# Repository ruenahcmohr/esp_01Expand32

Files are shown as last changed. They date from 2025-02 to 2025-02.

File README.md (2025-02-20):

# esp_01Expand32
esp-01 (esp8266) IO expander, 16 output, 16 input = 32

internet inspired esp-01 (esp8266) IO expander.

This uses DIP (socket and replace if you oops) 74xx595 and 74xx165 chips to give you 16 inputs and 16 outputs from an esp-01

Why not just use i2c?

 WELL, the i2c chips have realy primitive IO circuits, and you cannot have a high impedence input. This means you can't tie into analog circuits like RC pairs to give you time delays, which is something important to me.

 You also can't properly drive an output high, this is also important to me.

The zip file is all the gerber files to have it made.

The regultor is an AMS1117-3.3

oh yea, the power and IO are 5V., IF YOU WANT, you can bypass the regulator and use it all with 3.3V.

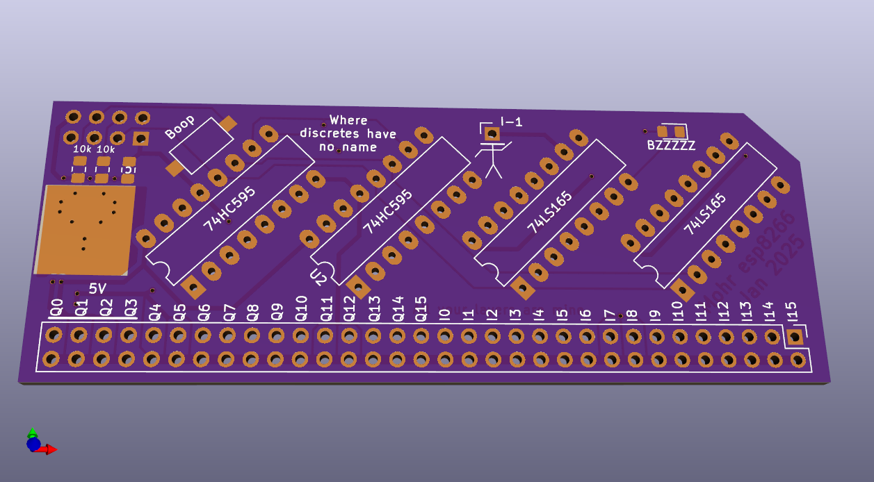
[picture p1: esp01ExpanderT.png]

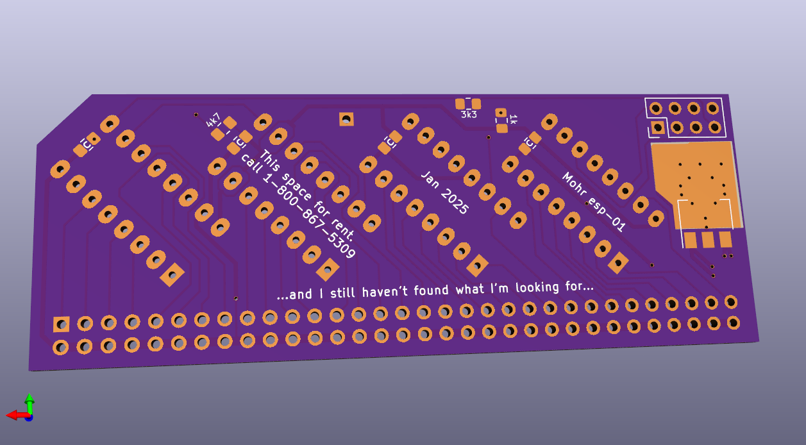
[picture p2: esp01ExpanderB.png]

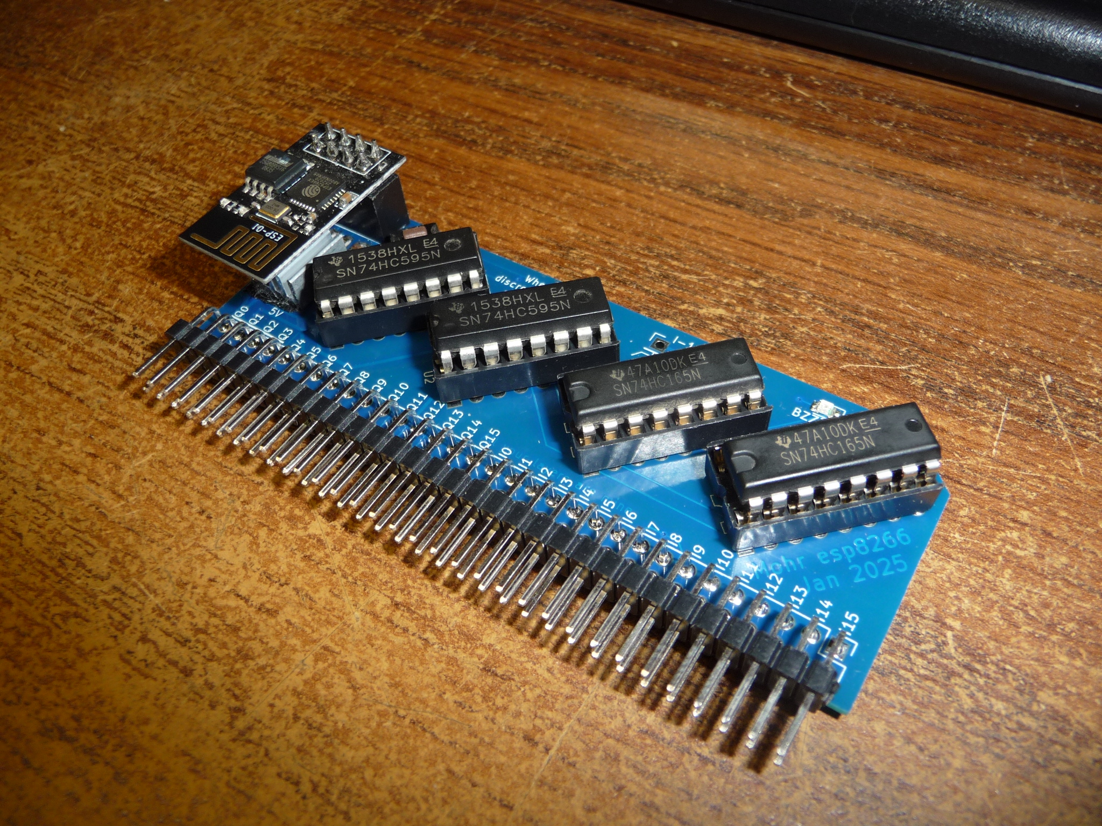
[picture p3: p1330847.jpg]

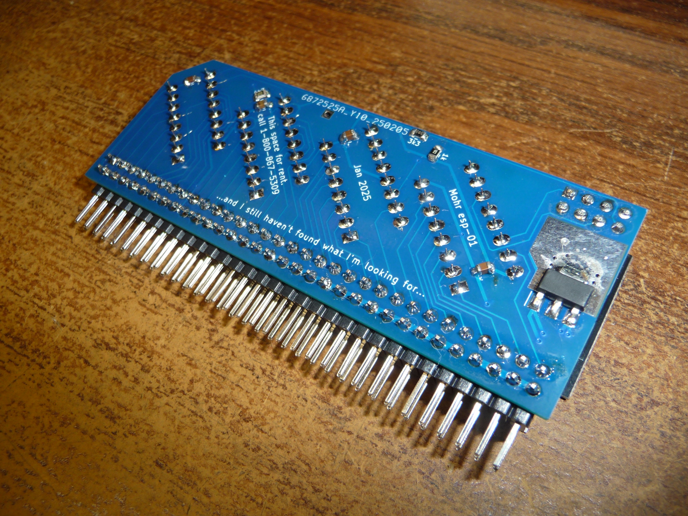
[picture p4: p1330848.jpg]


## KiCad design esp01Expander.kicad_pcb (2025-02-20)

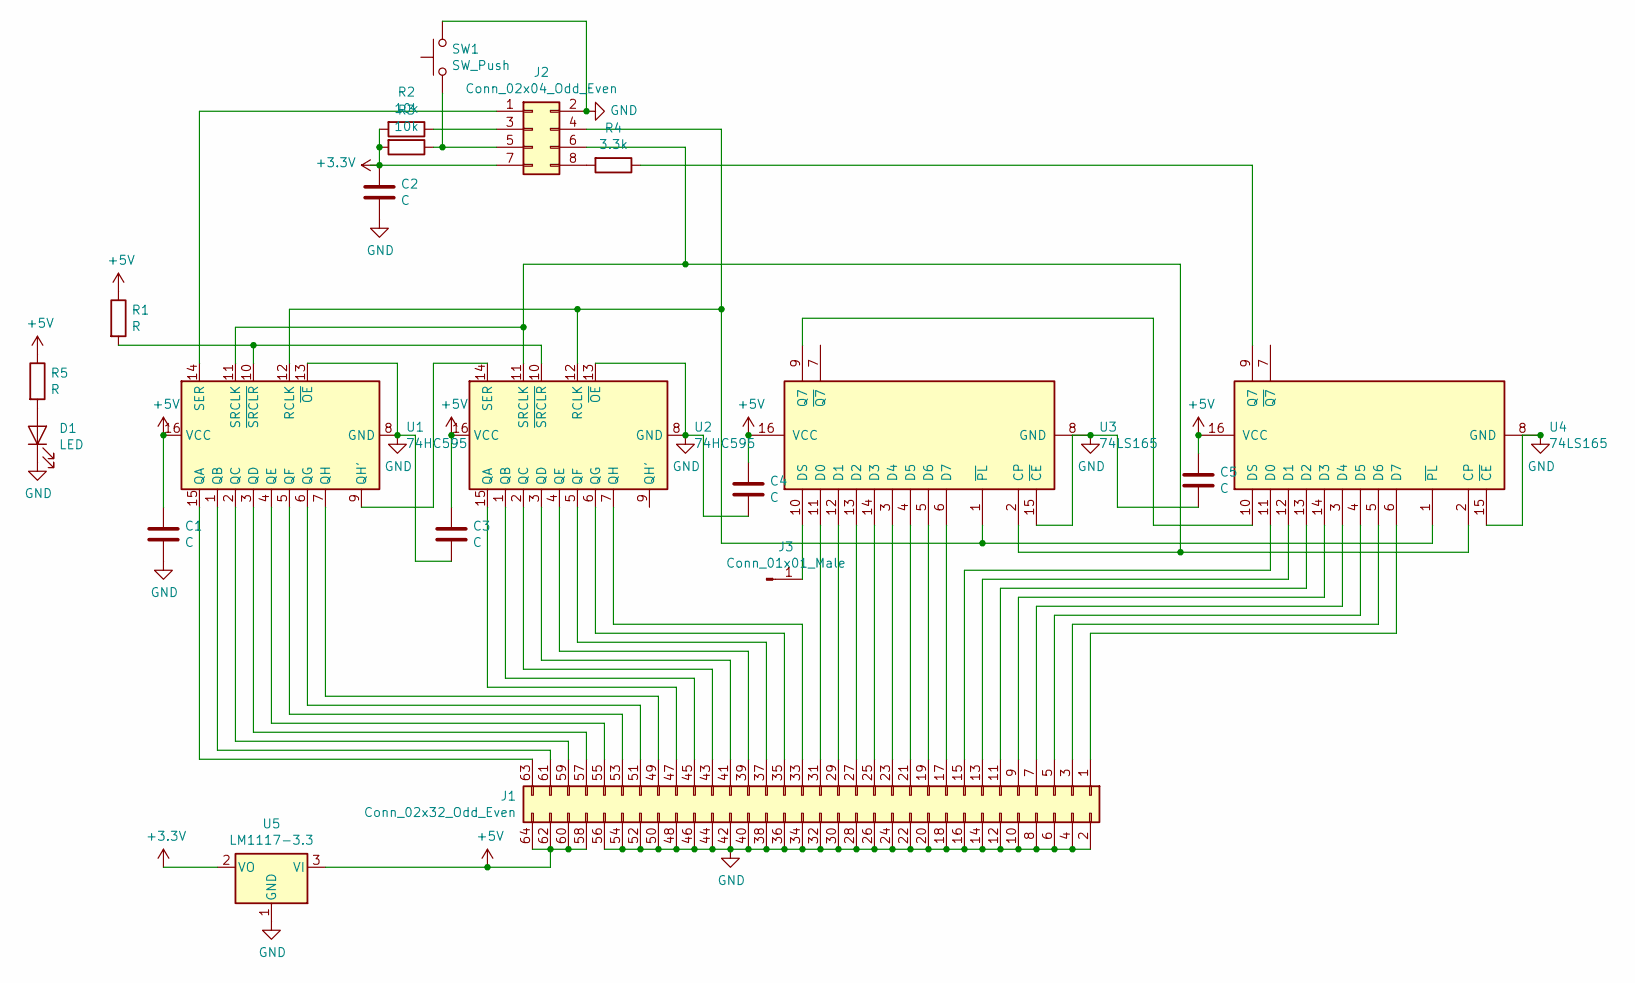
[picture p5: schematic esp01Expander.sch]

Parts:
C1, C2, C3, C4, C5: C; C_0805_2012Metric_Pad1.15x1.40mm_HandSolder
D1: LED; LED_0805_2012Metric_Pad1.15x1.40mm_HandSolder
J1: Conn_02x32_Odd_Even; PinHeader_2x32_P2.54mm_Vertical
J2: Conn_02x04_Odd_Even; PinHeader_2x04_P2.54mm_Vertical
J3: Conn_01x01_Male; PinHeader_1x01_P2.54mm_Vertical
R1, R5: R; R_0805_2012Metric_Pad1.15x1.40mm_HandSolder
R2, R3: 10k; R_0805_2012Metric_Pad1.15x1.40mm_HandSolder
R4: 3.3k; R_0805_2012Metric_Pad1.15x1.40mm_HandSolder
SW1: SW_Push; SW_SPST_CK_RS282G05A3
U1, U2: 74HC595; DIP-16_W7.62mm_LongPads
U3, U4: 74LS165; DIP-16_W7.62mm_LongPads
U5: LM1117-3.3; SOT-223-3_TabPin2

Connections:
+3V3: C2.1, J2.7, R2.2, R3.2, U5.2 (VO)
+5V: C1.1, C3.1, C4.1, C5.1, J1.58, J1.60, J1.62, J1.64, R1.1, R5.1, U1.16 (VCC), U2.16 (VCC), U3.16 (VCC), U4.16 (VCC), U5.3 (VI)
GND: C1.2, C2.2, C3.2, C4.2, C5.2, D1.1 (K), J1.2, J1.4, J1.6, J1.8, J1.10, J1.12, J1.14, J1.16, J1.18, J1.20, J1.22, J1.24, J1.26, J1.28, J1.30, J1.32, J1.34, J1.36, J1.38, J1.40, J1.42, J1.44, J1.46, J1.48, J1.50, J1.52, J1.54, J1.56, J2.2, SW1.2, U1.8 (GND), U1.13 (~OE), U2.8 (GND), U2.13 (~OE), U3.8 (GND), U3.15 (~CE), U4.8 (GND), U4.15 (~CE), U5.1 (GND)
unnamed: D1.2 (A), R5.2
unnamed: J1.1, U4.6 (D7)
unnamed: J1.3, U4.5 (D6)
unnamed: J1.5, U4.4 (D5)
unnamed: J1.7, U4.3 (D4)
unnamed: J1.9, U4.14 (D3)
unnamed: J1.11, U4.13 (D2)
unnamed: J1.13, U4.12 (D1)
unnamed: J1.15, U4.11 (D0)
unnamed: J1.17, U3.6 (D7)
unnamed: J1.19, U3.5 (D6)
unnamed: J1.21, U3.4 (D5)
unnamed: J1.23, U3.3 (D4)
unnamed: J1.25, U3.14 (D3)
unnamed: J1.27, U3.13 (D2)
unnamed: J1.29, U3.12 (D1)
unnamed: J1.31, U3.11 (D0)
unnamed: J1.33, U2.7 (QH)
unnamed: J1.35, U2.6 (QG)
unnamed: J1.37, U2.5 (QF)
unnamed: J1.39, U2.4 (QE)
unnamed: J1.41, U2.3 (QD)
unnamed: J1.43, U2.2 (QC)
unnamed: J1.45, U2.1 (QB)
unnamed: J1.47, U2.15 (QA)
unnamed: J1.49, U1.7 (QH)
unnamed: J1.51, U1.6 (QG)
unnamed: J1.53, U1.5 (QF)
unnamed: J1.55, U1.4 (QE)
unnamed: J1.57, U1.3 (QD)
unnamed: J1.59, U1.2 (QC)
unnamed: J1.61, U1.1 (QB)
unnamed: J1.63, U1.15 (QA)
unnamed: J2.1, U1.14 (SER)
unnamed: J2.3, R2.1
unnamed: J2.4, U1.12 (RCLK), U2.12 (RCLK), U3.1 (~PL), U4.1 (~PL)
unnamed: J2.5, R3.1, SW1.1
unnamed: J2.6, U1.11 (SRCLK), U2.11 (SRCLK), U3.2 (CP), U4.2 (CP)
unnamed: J2.8, R4.2
unnamed: J3.1, U3.10 (DS)
unnamed: R1.2, U1.10 (~SRCLR), U2.10 (~SRCLR)
unnamed: R4.1, U4.9 (Q7)
unnamed: U1.9 (QH'), U2.14 (SER)
unnamed: U3.9 (Q7), U4.10 (DS)

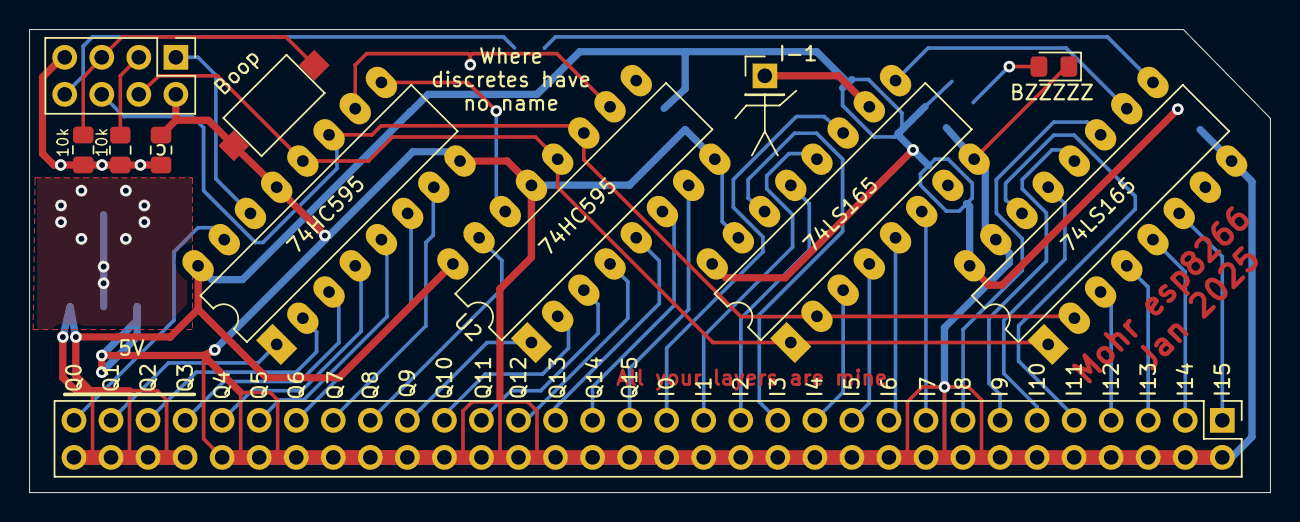
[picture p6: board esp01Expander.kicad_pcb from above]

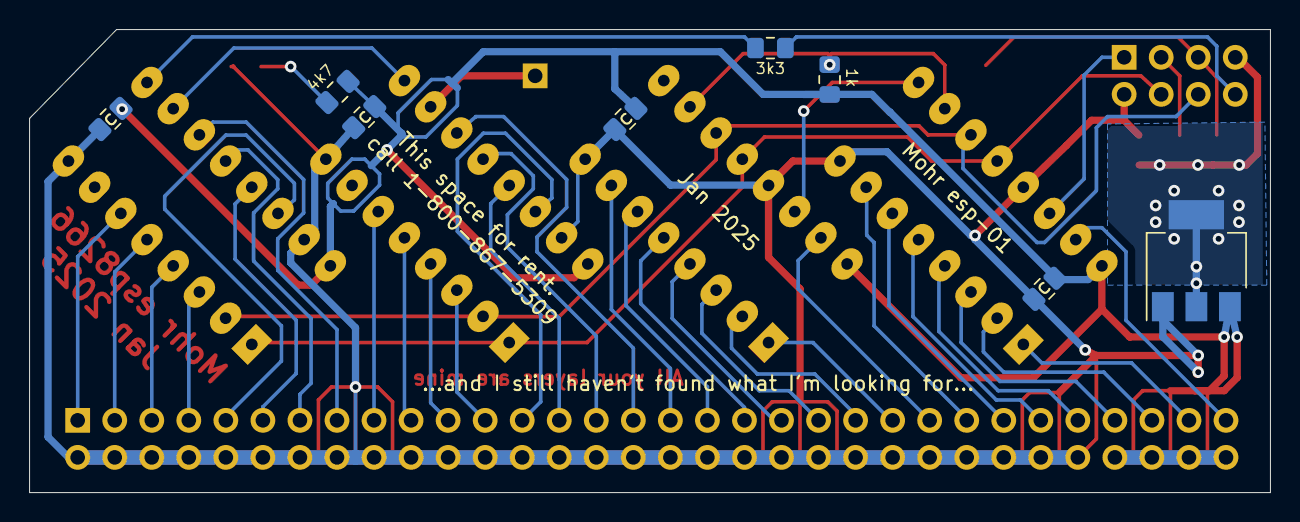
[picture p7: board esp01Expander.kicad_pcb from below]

Board: 2 copper layers, 85.1 x 31.8 mm, 20 parts (8 on the bottom side), 47 nets.

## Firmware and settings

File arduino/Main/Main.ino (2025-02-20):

/*
  8266 expander board project.
*/

#define DATAOUT  1
#define DATAIN   3
#define CLOCKLINE 0
#define STROBE    2

uint8_t shift(uint8_t out);


void setup() {
  pinMode(DATAOUT, OUTPUT);  
  
  pinMode(CLOCKLINE, OUTPUT);  
  digitalWrite(CLOCKLINE, LOW);
  
  pinMode(STROBE, OUTPUT);  
  digitalWrite(STROBE, LOW);
}


uint16_t i; // static storage for last read

void loop() {
  
  /*
  for (i = 1; i != 0; i <<= 1) {
    shift(i);
    delay(500);                      // Wait for two seconds (to demonstrate the active low LED)
  }
  */
  
  i = shift(i);
}


/*
 * Serial data exchange, we get 181kHz.
 * 
 */
uint16_t shift(uint16_t out) {
  
  uint16_t mask = 0x8000;
  uint16_t ret  = 0x0000;

  digitalWrite(STROBE, LOW);  // sample inputs 
  digitalWrite(STROBE, HIGH);
  
  while (mask) {
    if (out & mask) digitalWrite(DATAOUT, HIGH);
    else digitalWrite(DATAOUT, LOW);

    if (digitalRead(DATAIN) == HIGH) ret |= mask;
    
    digitalWrite(CLOCKLINE, HIGH); 
    digitalWrite(CLOCKLINE, LOW);
    mask >>= 1;
  }
  
  digitalWrite(STROBE, LOW);  
  digitalWrite(STROBE, HIGH); // latch outputs
  
  return ret;
}

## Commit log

2025-02-20 adding files
    [esp01Expander-B_Cu.gbr, esp01Expander-B_Mask.gbr, esp01Expander-B_Paste.gbr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]
2025-02-20 oh yea, and here is some arduino source code
